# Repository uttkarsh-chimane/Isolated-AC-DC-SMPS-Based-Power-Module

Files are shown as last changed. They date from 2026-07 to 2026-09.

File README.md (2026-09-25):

<h1 align="center">⚡ Isolated AC-DC SMPS-Based Power Supply using HLK-PM01</h1>

<p align="center">
  <a href="#-overview">Overview</a> •
  <a href="#-features">Features</a> •
  <a href="#%EF%B8%8F-hardware-architecture">Hardware Architecture</a> •
  <a href="#-schematic-highlights">Schematic Highlights</a> •
  <a href="#-pcb-design-insights">PCB Insights</a> •
  <a href="#-specifications">Specifications</a>
</p>

<p align="center">
  
  
  
  
  
</p>

<p align="center">
  A compact, isolated AC-to-DC Switch Mode Power Supply (SMPS) built around the HLK-PM01 module. The design incorporates comprehensive mains input protection, EMI suppression, primary-secondary galvanic isolation, and a regulated 5V DC output, making it suitable for embedded systems, IoT devices, and industrial electronics.
</p>

---

## 📖 Overview

This project presents the design of an **isolated 230VAC to 5VDC power supply** using the **HLK-PM01** AC-DC converter module. The objective was to develop a compact, safe, and reliable power supply suitable for powering embedded systems, microcontrollers, and IoT devices.

The design integrates the essential protection and filtering stages required for a mains-powered supply, including:

- **Input overcurrent protection** using a fuse
- **Inrush current limiting** using an NTC thermistor
- **Surge protection** using an MOV
- **EMI suppression** using X2 & Y2 safety capacitors and a bleeder resistor
- **Primary-secondary galvanic isolation**
- **Output filtering and transient protection** using electrolytic & ceramic capacitors and a TVS diode

---

## 📷 Project Gallery

🧩 **3D PCB Render**

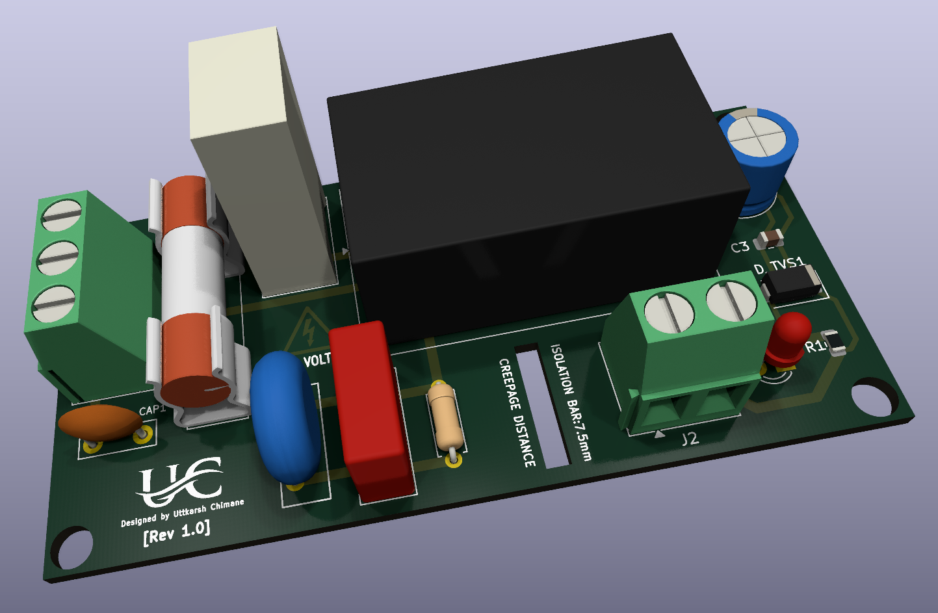
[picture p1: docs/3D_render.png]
3D PCB


🔌 **PCB Layout**

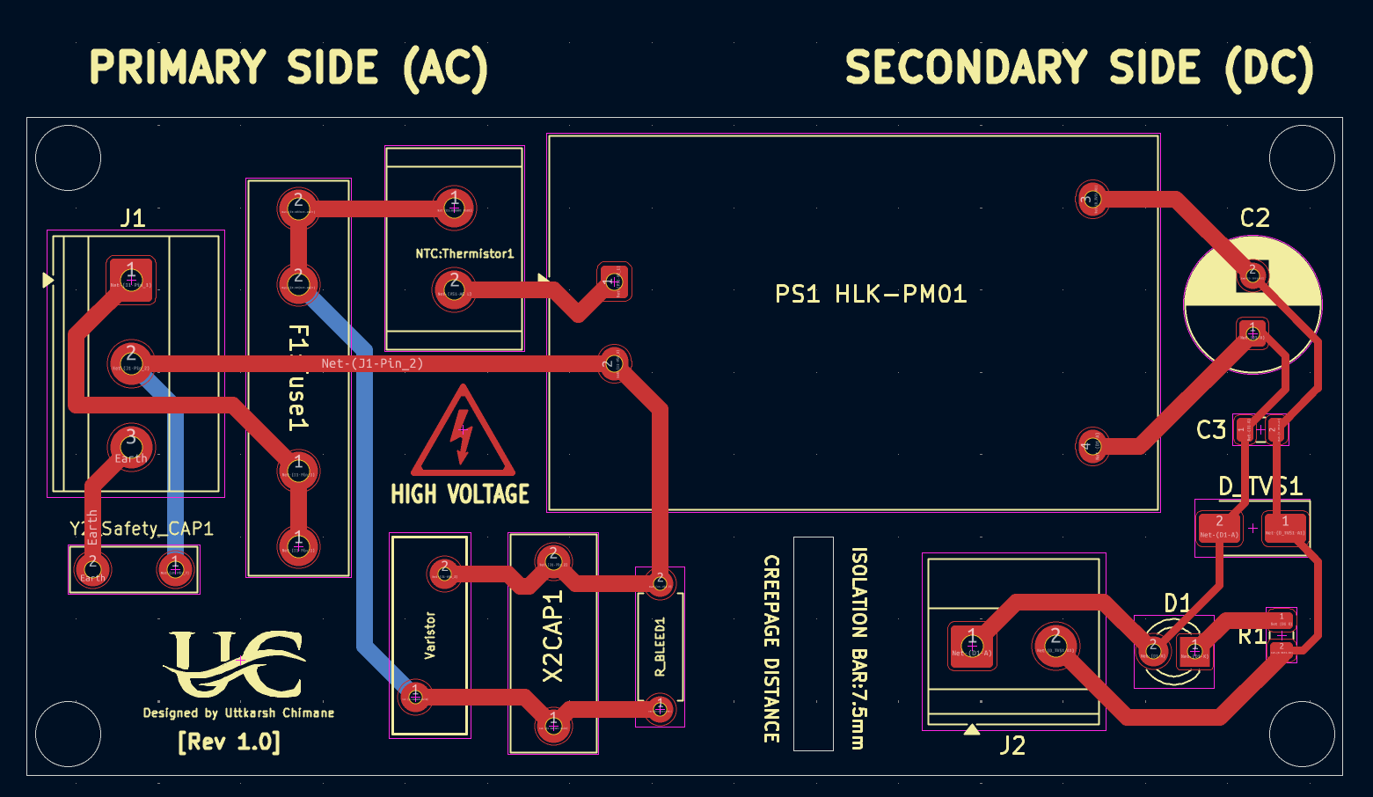
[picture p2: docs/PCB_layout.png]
PCB Layout


⚙️ **Schematic**

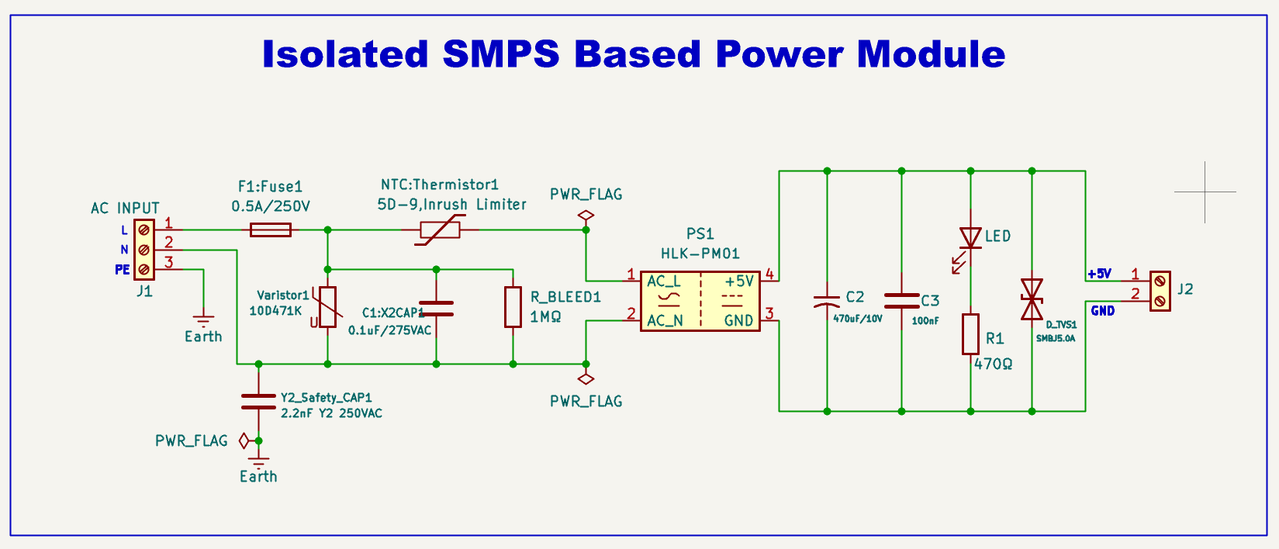
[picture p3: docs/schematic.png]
Schematic


---

## ✨ Features

- 230VAC input, regulated 5V DC output (see [Specifications](#-specifications) for current rating)
- Isolated design (HLK-PM01 module)
- Fuse protection
- MOV surge protection
- NTC inrush current limiter
- X2 EMI suppression capacitor
- Y2 safety capacitor
- Bleeder resistor
- Output filtering capacitors (electrolytic + ceramic)
- TVS diode protection on the output rail
- LED power indicator
- Compact single-layer PCB
- 7.5 mm creepage/clearance barrier (basic isolation — see note below)
- ERC passed, DRC passed

---

## ⚒️ Hardware Architecture

```
230VAC Input
      │
      ▼
 Fuse Protection
      │
      ▼
NTC Thermistor
      │
      ▼
 MOV + X2 Capacitor
      │
      ▼
 HLK-PM01
(Isolated AC-DC Module)
      │
      ▼
Output Filter
(470µF + 100nF)
      │
      ▼
 TVS Protection
      │
      ▼
LED Indicator
      │
      ▼
5V DC Output
```

---

## 📐 Schematic Highlights

**Input protection**
- 0.5A fuse
- 5D-9 NTC thermistor
- MOV (10D471K)

**EMI suppression**
- X2 safety capacitor
- Y2 safety capacitor
- 1MΩ bleeder resistor

**Power conversion**
- HLK-PM01 isolated AC-DC module (230VAC in, 5V DC out)

**Output stage**
- 470µF electrolytic capacitor
- 100nF ceramic capacitor
- SMBJ5.0A TVS diode (clamps ~9.2V — chosen for fast transient suppression while keeping standoff comfortably above the 5V rail)
- LED status indicator

---

## 🧩 PCB Design Insights

- Designed in **KiCad 10**
- Single-layer PCB
- Primary-secondary isolation maintained throughout layout
- 7.5 mm creepage/clearance barrier — sized for **basic insulation** at this voltage/pollution degree; reinforced insulation per IEC 62368-1 typically calls for wider spacing, so treat this as basic-isolation-only unless re-verified against the applicable standard
- Thick power traces for mains current
- Compact component placement
- ERC: 0 errors
- DRC: 0 errors
- Custom silkscreen labels
- Mounting holes included

---

## 🧪 Applications

- ESP32 / Arduino projects
- IoT devices
- Embedded systems
- Home automation
- Sensor nodes
- Industrial monitoring
- Educational / prototype development

---

## ⚠️ Limitations

- Fixed 5V output
- Output power limited by the HLK-PM01 module's rating
- No short-circuit indicator
- No reverse polarity protection on the output
- No output fuse — input fuse protects against mains-side faults only, not secondary-side shorts
- Indoor use only
- Requires a proper enclosure for mains safety

---

## 🚀 Future Improvements

- Add output fuse
- Add reverse polarity protection
- Add power ON switch
- Add AC power LED
- Improve thermal management
- Add test points
- Add mounting labels
- Design a double-layer version
- Add IEC input connector
- Improve EMI filtering

---

## 📚 Learning Outcomes

- PCB design using KiCad
- AC-DC power supply design
- Electrical isolation concepts (creepage & clearance)
- Component footprint selection
- PCB routing techniques
- EMI suppression methods
- Mains safety practices
- Design Rule Check (DRC) and Electrical Rule Check (ERC)
- PCB 3D visualization

---

## 📊 Specifications

| **Parameter** | **Value** |
|:---|:---|
| **Project** | Isolated 230VAC to 5VDC Power Supply using HLK-PM01 |
| **Input Voltage** | 230 VAC, 50 Hz |
| **Output Voltage** | 5 V DC |
| **Output Power** | 3 W |
| **Output Current** | Up to 600 mA |
| **AC-DC Module** | Hi-Link HLK-PM01 |
| **Input Protection** | 0.5 A Fuse, MOV (10D471K), 5D-9 NTC |
| **EMI Filter** | X2 Capacitor, Y2 Capacitor, 1 MΩ Bleeder |
| **Output Protection** | SMBJ5.0A TVS Diode |
| **Output Filter** | 470 µF + 100 nF Capacitors |
| **Isolation** | Galvanically Isolated (basic, 7.5 mm barrier) |
| **PCB** | Single-Layer FR-4 |
| **Design Software** | KiCad 10 |
| **ERC Status** | ✅ Passed (0 Errors) |
| **DRC Status** | ✅ Passed (0 Errors) |
| **Applications** | ESP32, Arduino, IoT, Embedded Systems |

---

## 👨‍💻 Author

**Uttkarsh Chimane**
---

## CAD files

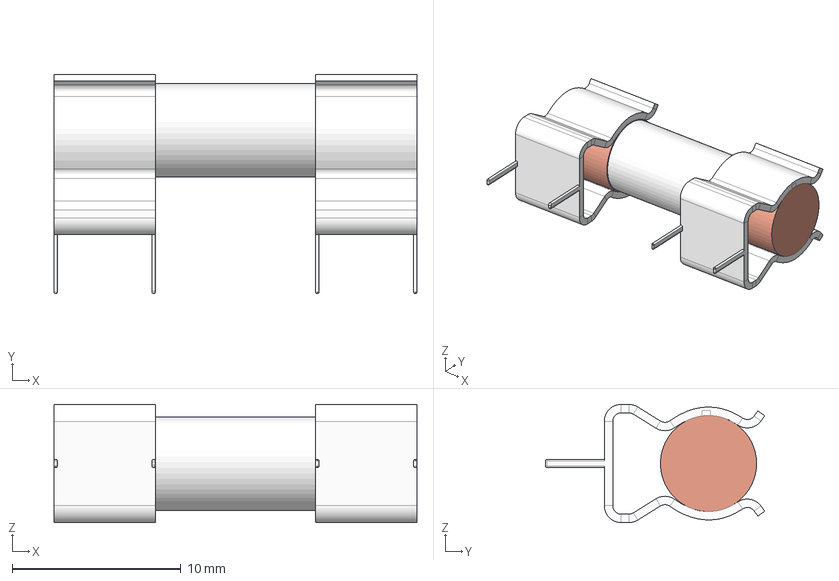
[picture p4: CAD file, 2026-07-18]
hardware/3D model/FUSE_CLIP.stp
21.5 x 13.0 x 7.00 mm

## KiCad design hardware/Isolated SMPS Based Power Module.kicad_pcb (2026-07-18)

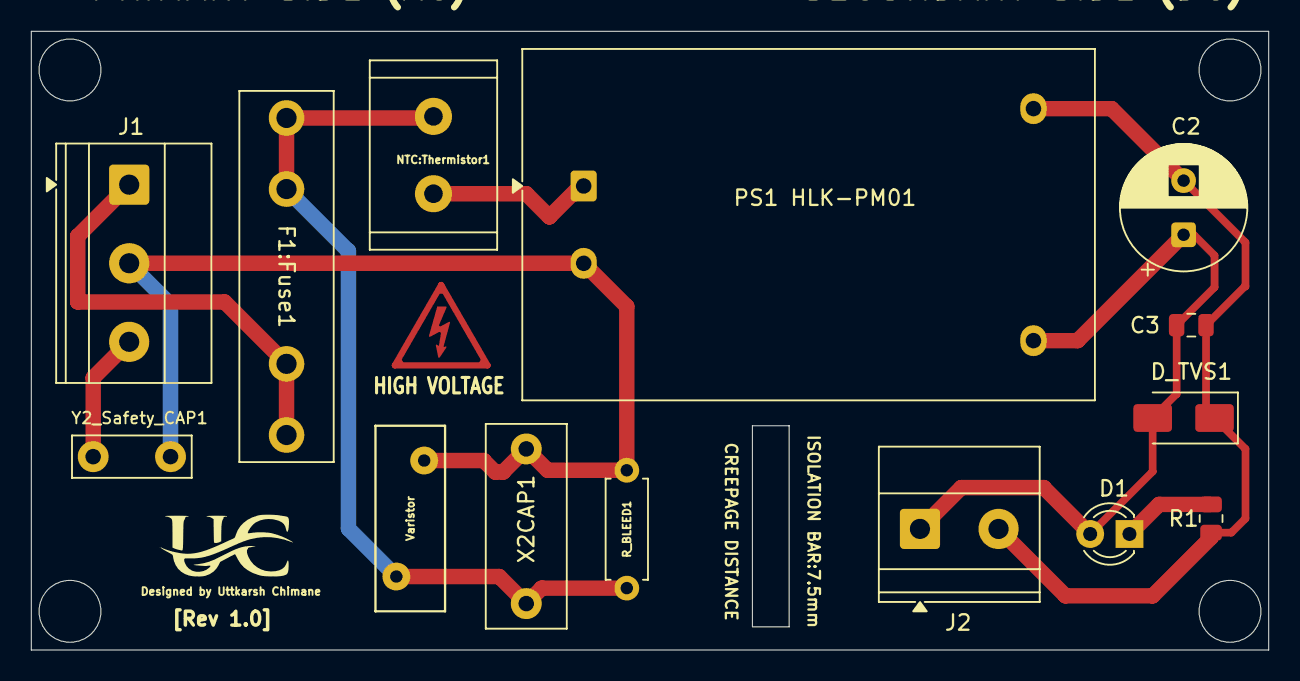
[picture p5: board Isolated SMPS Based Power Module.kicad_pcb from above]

Board: 2 copper layers, 80.0 x 40.0 mm, 14 parts (0 on the bottom side), 8 nets.

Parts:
C2: 470uF/10V; CP_Radial_D8.0mm_P3.50mm
C3: 100nF; C_0805_2012Metric
D1: LED; LED_D3.0mm
D_TVS1: SMBJ5.0A; D_SMA
F1:Fuse1: 0.5A/250V; Fuseholder_Littelfuse_100_series_5x20mm
J1: AC INPUT; TerminalBlock_Phoenix_MKDS-1,5-3-5.08_1x03_P5.08mm_Horizont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
J2: Screw_Terminal_01x02; TerminalBlock_Phoenix_MKDS-1,5-2-5.08_1x02_P5.08mm_Horizont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
NTC:Thermistor1: 5D-9,Inrush Limiter; R_Radial_Power_L12.0mm_W8.0mm_P5.00mm
PS1 HLK-PM01: HLK-PM01; Converter_ACDC_Hi-Link_HLK-PMxx
R1: 470Ω; R_0805_2012Metric
R_BLEED1: 1MΩ; R_Axial_DIN0207_L6.3mm_D2.5mm_P7.62mm_Horizontal
Varistor: 10D471K; RV_Disc_D12mm_W4.5mm_P7.5mm
X2CAP1: 0.1uF/275VAC; C_Rect_L13.0mm_W5.0mm_P10.00mm_FKS3_FKP3_MKS4
Y2_Safety_CAP1: 2.2nF Y2 250VAC; C_Disc_D7.5mm_W2.5mm_P5.00mm

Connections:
Earth: J1.3, Y2_Safety_CAP1.2
unnamed: F1:Fuse1.2, NTC:Thermistor1.1, R_BLEED1.1, Varistor.1, X2CAP1.1
unnamed: C2.1, C3.1, D1.2 (A), D_TVS1.2 (A2), J2.1, PS1 HLK-PM01.4 (+5V)
unnamed: D1.1 (K), R1.1
unnamed: C2.2, C3.2, D_TVS1.1 (A1), J2.2, PS1 HLK-PM01.3 (GND), R1.2
unnamed: F1:Fuse1.1, J1.1
unnamed: J1.2, PS1 HLK-PM01.2 (AC_N), R_BLEED1.2, Varistor.2, X2CAP1.2, Y2_Safety_CAP1.1
unnamed: NTC:Thermistor1.2, PS1 HLK-PM01.1 (AC_L)
